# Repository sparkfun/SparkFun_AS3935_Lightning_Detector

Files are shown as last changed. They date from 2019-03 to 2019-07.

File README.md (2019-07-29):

 SparkFun AS3935 Lightning Detector
========================================

SparkFun AS3935 Lightning Detector (https://www.sparkfun.com/products/15441)

[*SparkFun AS3935 Lightning Detector (SEN-15441)*](https://www.sparkfun.com/products/15441)

The SparkFun Lightning Detector adds lightning detection to your next weather station to make sure you are aware of any potential hazardous weather heading your way. The AS3935 is capable of detecting lightning up to 40km away with an accuracy of 1km to the storm front with a sensitive antenna tuned to pick up lightning events in the 500kHz band. 

There are a number of sources that can cause false positives but the lightning detector itself can reliably filter these out by default. If not, we've made sure to include settings you can configure using the lightning detector library to increase the chip's robustness to noise and false positives. The lightning detector library also gives you access to settings such as storm sensing sensitivity when detecting indoors vs outdoors, or the number of lightning strikes needed to trigger an interrupt.

Repository Contents
-------------------

* **/Documentation** - Datasheets, additional product information
* **/Hardware** - Eagle design files (.brd, .sch)

Documentation
--------------
* **[Installing an Arduino Library](https://learn.sparkfun.com/tutorials/installing-an-arduino-library/)** - Basic instructions on installing an Arduino library
* **[Library](https://github.com/sparkfun/SparkFun_AS3935_Lightning_Detector_Arduino_Library)** - Arduino library for the AS3935 Lightning Detector
* **[Hookup Guide](https://learn.sparkfun.com/tutorials/sparkfun-as3935-lightning-detector-hookup-guide-v20)** - Hookup Guide for the SparkFun AS3935 Lightning Detector

Product Versions
--------------
* [SEN-15441](https://www.sparkfun.com/products/15441) - SparkFun SPI version
* [SEN-15276](https://www.sparkfun.com/products/15276) - SparkFun I2C version
* [SPX-15057](https://www.sparkfun.com/products/retired/15057) - SparkX version

License Information
-------------------

This product is _**open source**_! 

Please review the LICENSE.md file for license information.

If you have any questions or concerns on licensing, please contact technical support on our [SparkFun forums](https://forum.sparkfun.com/viewforum.php?f=152).

Please use, reuse, and modify these files as you see fit. Please maintain attribution to SparkFun Electronics and release under the same license.

Distributed as-is; no warranty is given.

- Your friends at SparkFun.

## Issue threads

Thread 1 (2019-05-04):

Error compiling when using Huzzah ESP8266 or Adafruit Feather M0 board

Loopbackconnector, 2019-05-04:
When compiling Example1_BasicLightning and using either Huzzah  ESP8266 or Adafruit Feather M0 as the board type I get the following error:

Example1_BasicLightning:33:38: error: invalid conversion from 'int' to 'i2cAddress {aka SF_AS3935_I2C_ADDRESS}' [-fpermissive]
 SparkFun_AS3935 lightning(AS3935_ADDR);

edspark, 2019-05-06:
Thanks for the issue, I'll get on this sometime in the next few days. Thanks for your patience!

edspark, 2019-05-09:
In the future this is best filed underneath the library [repo](https://github.com/sparkfun/SparkFun_AS3935_Lightning_Detector_Arduino_Library), since it is a library issue. It was fixed with this commit: https://github.com/sparkfun/SparkFun_AS3935_Lightning_Detector_Arduino_Library/commit/271d5d1f4748dea87de263077b5cf0d9d4602a8f

Closed 2019-05-09.

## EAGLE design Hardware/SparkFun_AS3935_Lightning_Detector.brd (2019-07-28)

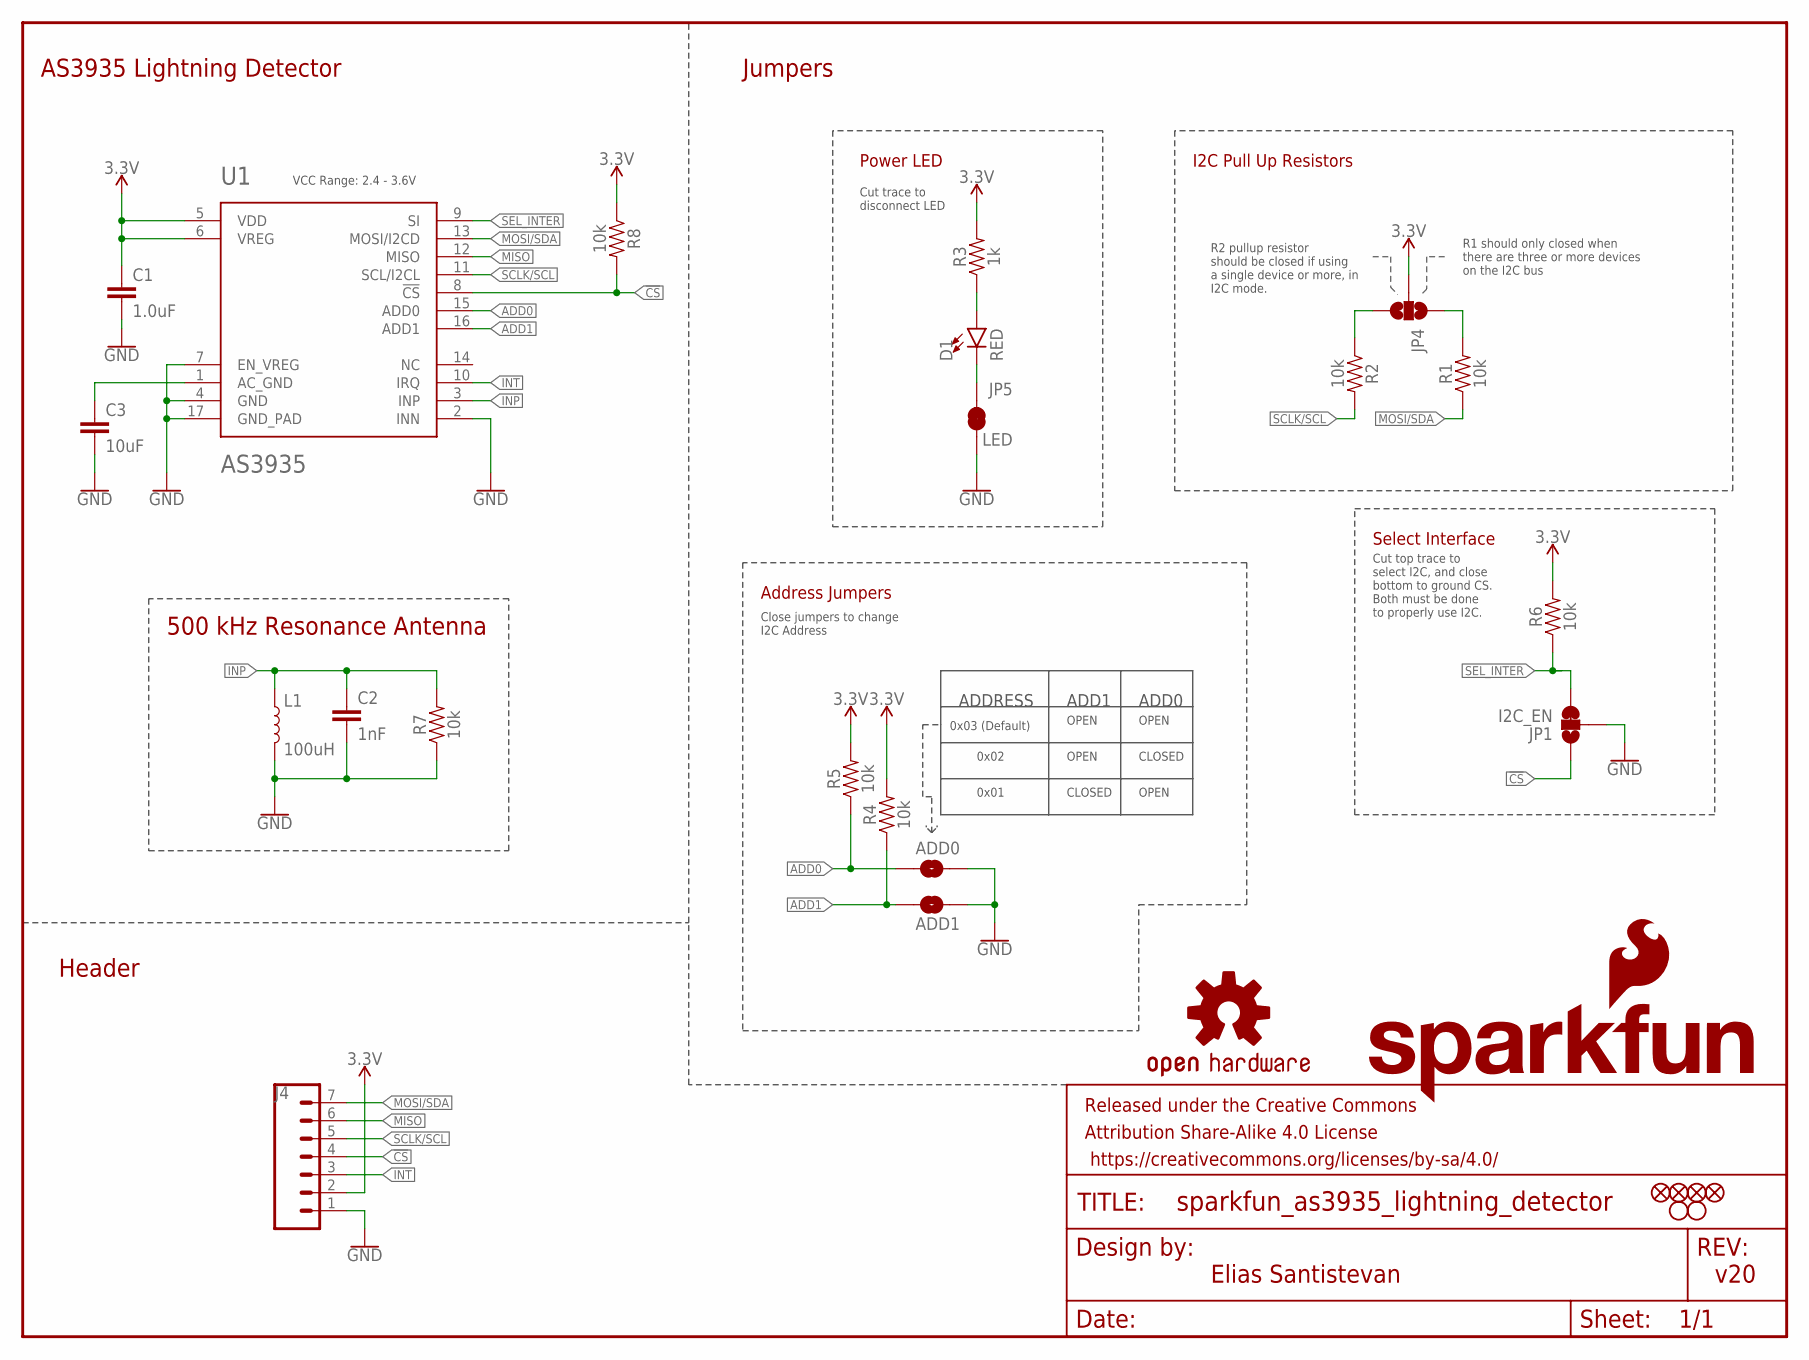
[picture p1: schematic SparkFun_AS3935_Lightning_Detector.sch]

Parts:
ADD0, ADD1: JUMPER-SMT_2_NO_SILK; SMT-JUMPER_2_NO_SILK
C1: 1.0uF; 0603
C2: 1nF; 0603
C3: 10uF; 0603
D1: RED; LED-0603
FD1, FD2, FD3, FD4: FIDUCIAL1X2; FIDUCIAL-1X2
FRAME1: FRAME-LETTER; CREATIVE_COMMONS
H1, H2: STAND-OFFTIGHT; STAND-OFF-TIGHT
J4: CONN_07NO_SILK; 1X07_NO_SILK
JP1: I2C_EN; SMT-JUMPER_3_1-NC_TRACE_SILK
JP4: JUMPER-SMT_3_NO_SILK; SMT-JUMPER_3_NO_SILK
JP5: LED; SMT-JUMPER_2_NC_TRACE_SILK
L1: 100uH; MA5532-AE
LOGO1: OSHW-LOGOS; OSHW-LOGO-S
LOGO2: SFE_LOGO_NAME.1_INCH; SFE_LOGO_NAME_.1
LOGO3: SFE_LOGO_FLAME.2_INCH; SFE_LOGO_FLAME_.2
R1, R2, R4, R5, R6, R7, R8: 10k; 0603
R3: 1k; 0603
U1: AS3935; 16LD_MLPQ

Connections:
3.3V: C1.1, J4.2, JP4.2, R3.2, R4.2, R5.2, R6.2, R8.1, U1.5 (VDD), U1.6 (VREG)
!CS: J4.4, JP1.1, R8.2, U1.8 (!CS)
ADD0: ADD0.1, R5.1, U1.15 (ADD0)
ADD1: ADD1.1, R4.1, U1.16 (ADD1)
GND: ADD0.2, ADD1.2, C1.2, C2.2, C3.2, J4.1, JP1.2, JP5.1, L1.2, R7.1, U1.2 (INN), U1.4 (GND), U1.7 (EN_VREG), U1.17 (GND_PAD)
INP: C2.1, L1.1, R7.2, U1.3 (INP)
INT: J4.3, U1.10 (IRQ)
MISO: J4.6, U1.12 (MISO)
MOSI/SDA: J4.7, R1.1, U1.13 (MOSI/I2CD)
unnamed: D1.A, R3.1
unnamed: C3.1, U1.1 (AC_GND)
unnamed: JP4.1, R1.2
unnamed: JP4.3, R2.1
unnamed: D1.C, JP5.2
SCLK/SCL: J4.5, R2.2, U1.11 (SCL/I2CL)
SEL_INTER: JP1.3, R6.1, U1.9 (SI)

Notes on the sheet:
Elias Santistevan
v20
AS3935 Lightning Detector
Jumpers
Header
500 kHz Resonance Antenna
R1 should only closed when there are three or more devices on the I2C bus
Close jumpers to change I2C Address
ADD0
ADD1
OPEN
CLOSED
ADDRESS
0x03 (Default)
0x02
VCC Range: 2.4 - 3.6V
Cut trace to disconnect LED
0x01
R2 pullup resistor should be closed if using a single device or more, in I2C mode.
Power LED
I2C Pull Up Resistors
Address Jumpers
Select Interface
Cut top trace to select I2C, and close bottom to ground CS. Both must be done to properly use I2C.

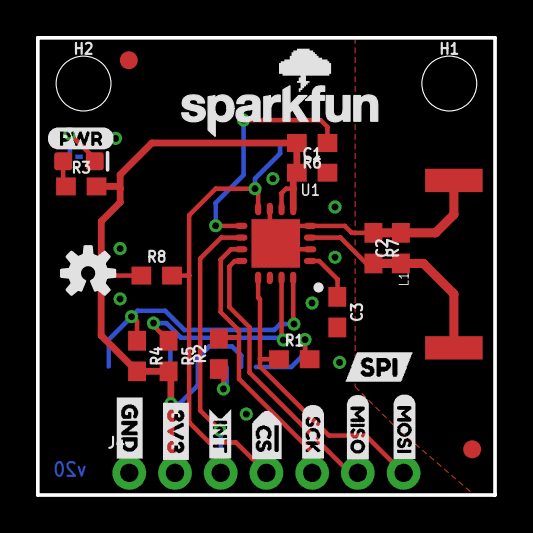
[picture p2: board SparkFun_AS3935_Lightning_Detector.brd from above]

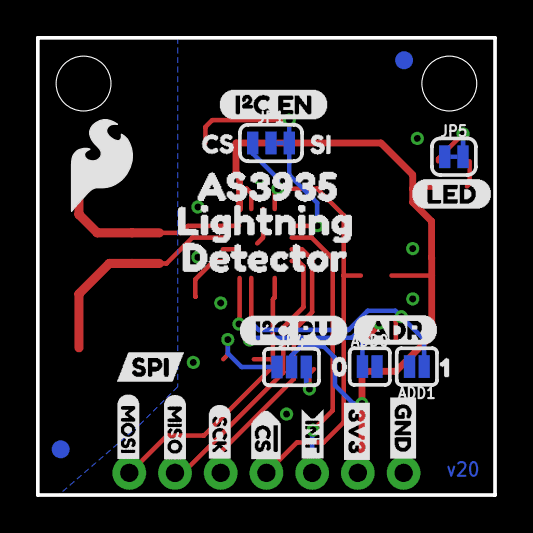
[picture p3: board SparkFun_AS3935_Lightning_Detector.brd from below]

Board: 2 copper layers, 25.4 x 25.4 mm, 59 parts (27 on the bottom side), 16 nets.

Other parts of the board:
U$1: LED0
U$2, U$10: GND-03
U$3, U$15: SPI1
U$4, U$18: 3V3-03
U$5, U$30: #CS0
U$6: AS39350
U$7: LIGHTNING0
U$8, U$23: SCK-(]-03
U$9, U$12: MISO-(]-03
U$11, U$22: MOSI-(]-03
U$13, U$14: INT0
U$16: CS0
U$17: I#C_EN0
U$19: SI1
U$32: PWR-()-03
U$33: ADR-()-04
U$34: I#C_PU0
U$36: 10
U$37: 00
U$39: DETECTOR0
U$40: ##0

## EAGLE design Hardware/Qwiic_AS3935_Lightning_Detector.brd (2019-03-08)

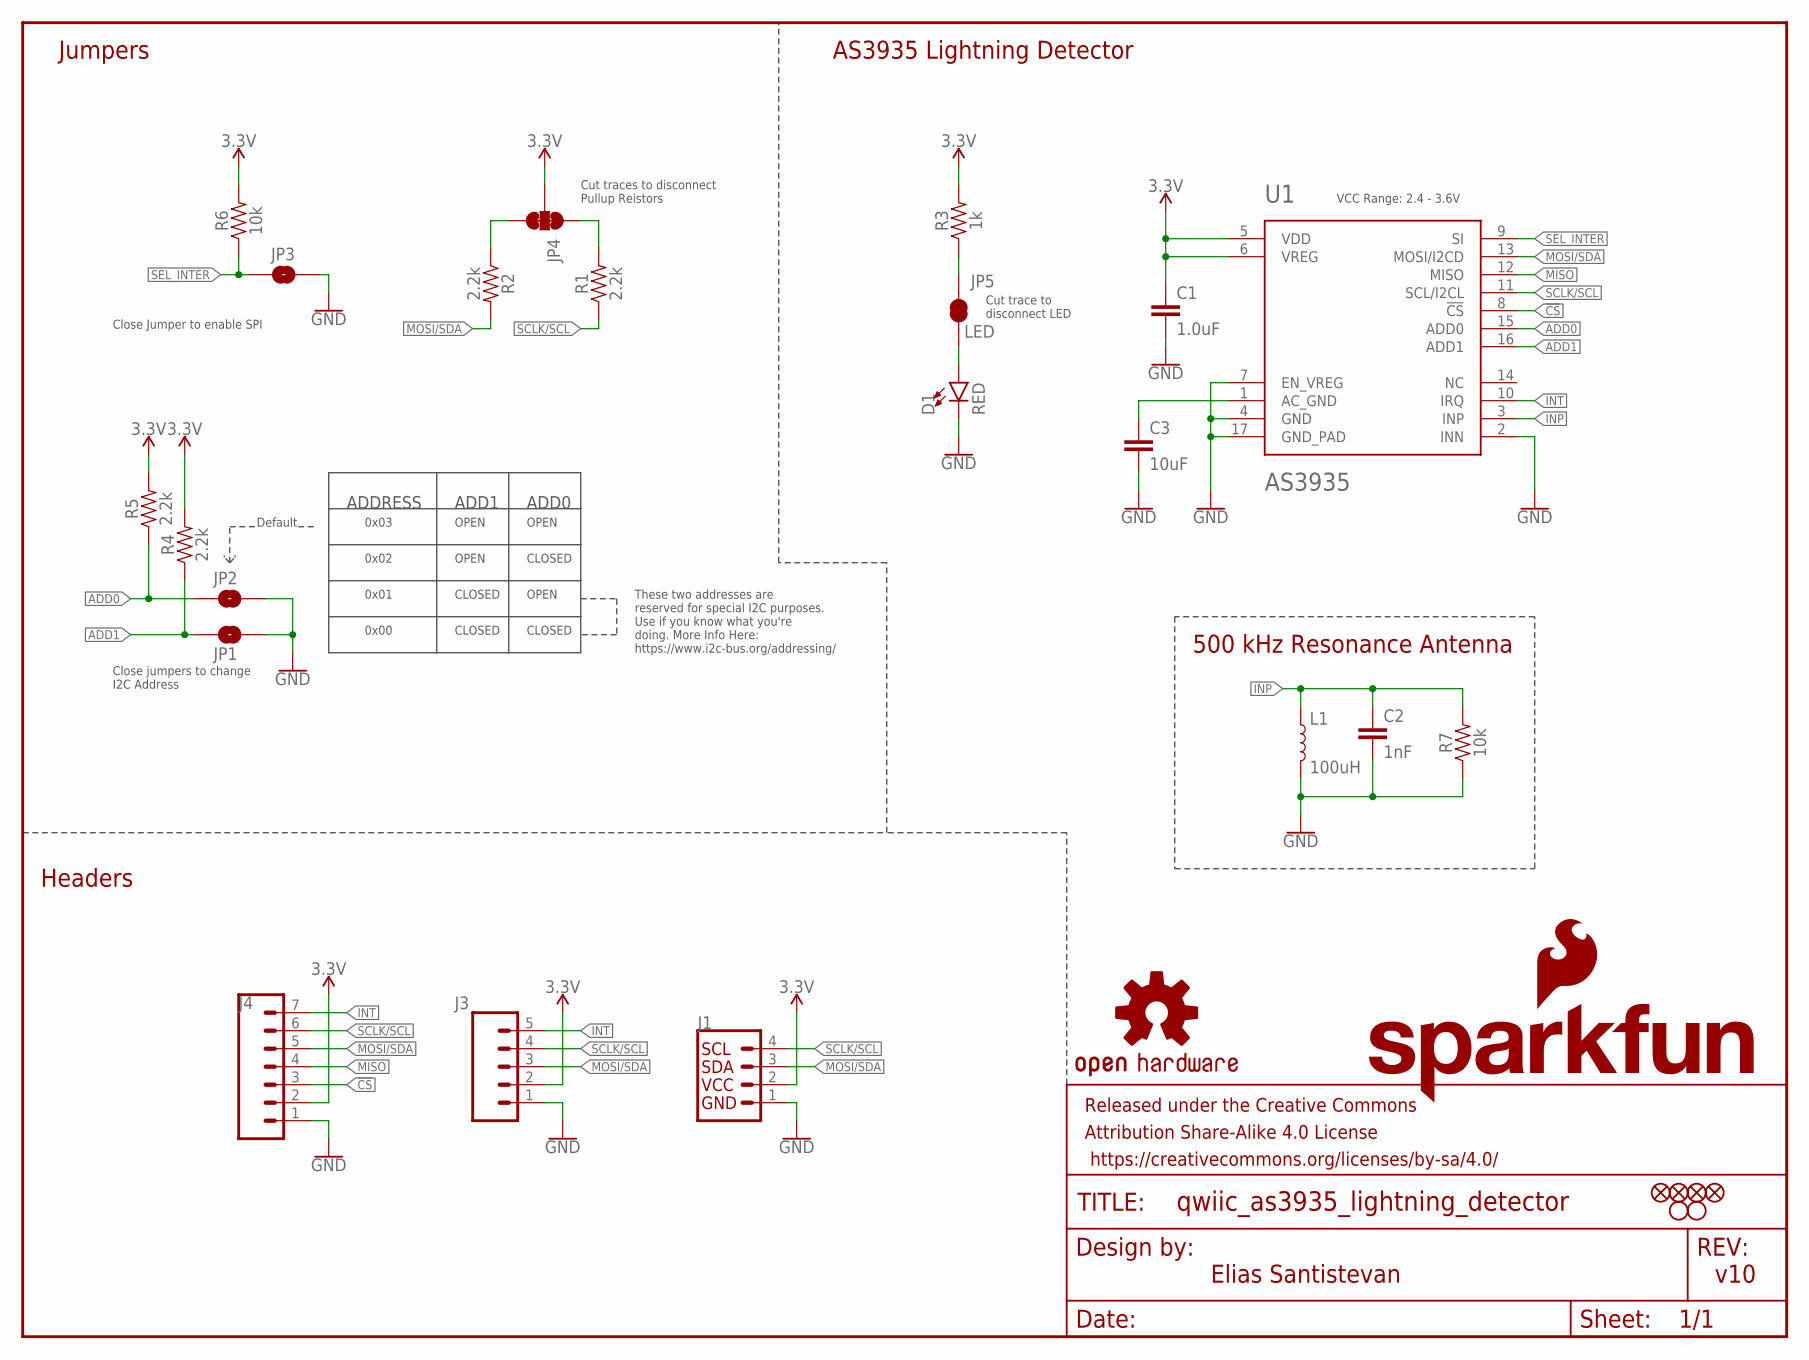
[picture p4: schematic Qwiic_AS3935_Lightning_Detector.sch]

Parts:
C1: 1.0uF; 0603
C2: 1nF; 0603
C3: 10uF; 0603
D1: RED; LED-0603
FD1, FD2, FD3, FD4: FIDUCIAL1X2; FIDUCIAL-1X2
FRAME1: FRAME-LETTER; CREATIVE_COMMONS
H1, H2: STAND-OFFTIGHT; STAND-OFF-TIGHT
J1: QWIIC_CONNECTORJS-1MM; JST04_1MM_RA
J3: CONN_05NO_SILK; 1X05_NO_SILK
J4: CONN_07NO_SILK; 1X07_NO_SILK
JP1, JP2, JP3: JUMPER-SMT_2_NO_SILK; SMT-JUMPER_2_NO_SILK
JP4: JUMPER-SMT_3_2-NC_TRACE_SILK; SMT-JUMPER_3_2-NC_TRACE_SILK
JP5: LED; SMT-JUMPER_2_NC_TRACE_SILK
L1: 100uH; MA5532-AE
LOGO1: OSHW-LOGOS; OSHW-LOGO-S
LOGO2: SFE_LOGO_NAME.1_INCH; SFE_LOGO_NAME_.1
LOGO3: SFE_LOGO_FLAME.1_INCH; SFE_LOGO_FLAME_.1
R1, R2, R4, R5: 2.2k; 0603
R3: 1k; 0603
R6, R7: 10k; 0603
U1: AS3935; 16LD_MLPQ

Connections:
3.3V: C1.1, J1.2, J3.2, J4.2, JP4.2, R3.2, R4.2, R5.2, R6.2, U1.5 (VDD), U1.6 (VREG)
!CS: J4.3, U1.8 (!CS)
ADD0: JP2.1, R5.1, U1.15 (ADD0)
ADD1: JP1.1, R4.1, U1.16 (ADD1)
GND: C1.2, C2.2, C3.2, D1.C, J1.1, J3.1, J4.1, JP1.2, JP2.2, JP3.2, L1.2, R7.1, U1.2 (INN), U1.4 (GND), U1.7 (EN_VREG), U1.17 (GND_PAD)
INP: C2.1, L1.1, R7.2, U1.3 (INP)
INT: J3.5, J4.7, U1.10 (IRQ)
MISO: J4.4, U1.12 (MISO)
MOSI/SDA: J1.3, J3.3, J4.5, R2.2, U1.13 (MOSI/I2CD)
unnamed: JP5.2, R3.1
unnamed: C3.1, U1.1 (AC_GND)
unnamed: JP4.1, R1.2
unnamed: JP4.3, R2.1
unnamed: D1.A, JP5.1
SCLK/SCL: J1.4, J3.4, J4.6, R1.1, U1.11 (SCL/I2CL)
SEL_INTER: JP3.1, R6.1, U1.9 (SI)

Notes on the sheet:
Elias Santistevan
v10
AS3935 Lightning Detector
Jumpers
Headers
500 kHz Resonance Antenna
Close Jumper to enable SPI
Cut traces to disconnect Pullup Reistors
Close jumpers to change I2C Address
ADD0
ADD1
OPEN
CLOSED
ADDRESS
0x03
0x02
Default
VCC Range: 2.4 - 3.6V
Cut trace to disconnect LED
0x01
0x00
These two addresses are reserved for special I2C purposes. Use if you know what you're doing. More Info Here: https://www.i2c-bus.org/addressing/

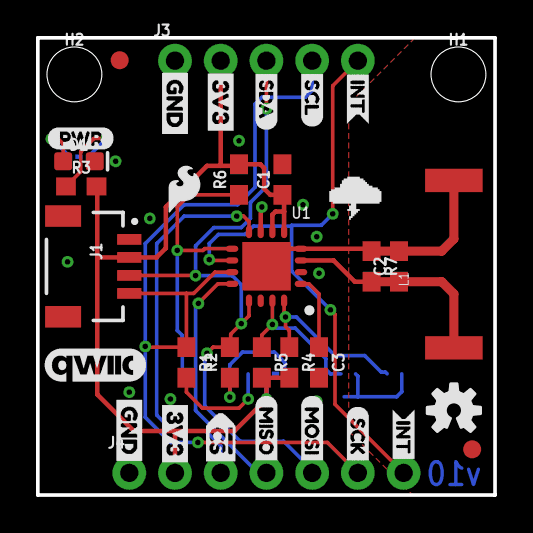
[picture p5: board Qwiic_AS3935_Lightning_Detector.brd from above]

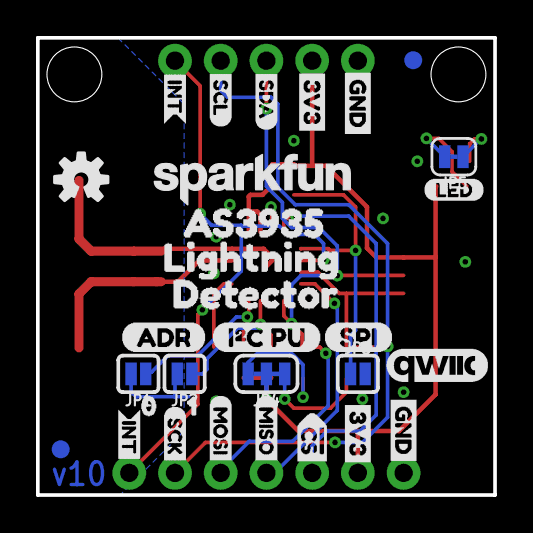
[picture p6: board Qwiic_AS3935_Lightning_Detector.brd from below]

Board: 2 copper layers, 25.4 x 25.4 mm, 69 parts (31 on the bottom side), 16 nets.

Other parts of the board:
U$1: LED0
U$3, U$4: QWIIC_COPYRIGHT_SMALL
U$6: AS39350
U$7: LIGHTNING0
U$8, U$9, U$10, U$38: GND-03
U$11: CS#-<]-04
U$12, U$13: MISO-(]-03
U$14, U$15, U$24, U$29: INT0
U$16, U$22: MOSI-(]-03
U$17, U$18, U$20, U$21: 3V3-03
U$19, U$23: SCK-(]-03
U$25, U$26: SDA0
U$27, U$28: SCL0
U$30: #CS0
U$31: OSHW-LOGO-S
U$32: PWR-()-03
U$33: ADR-()-04
U$34: I#C_PU0
U$35: SPI0
U$36: 10
U$37: 00
U$39: DETECTOR0
U$40: ##0

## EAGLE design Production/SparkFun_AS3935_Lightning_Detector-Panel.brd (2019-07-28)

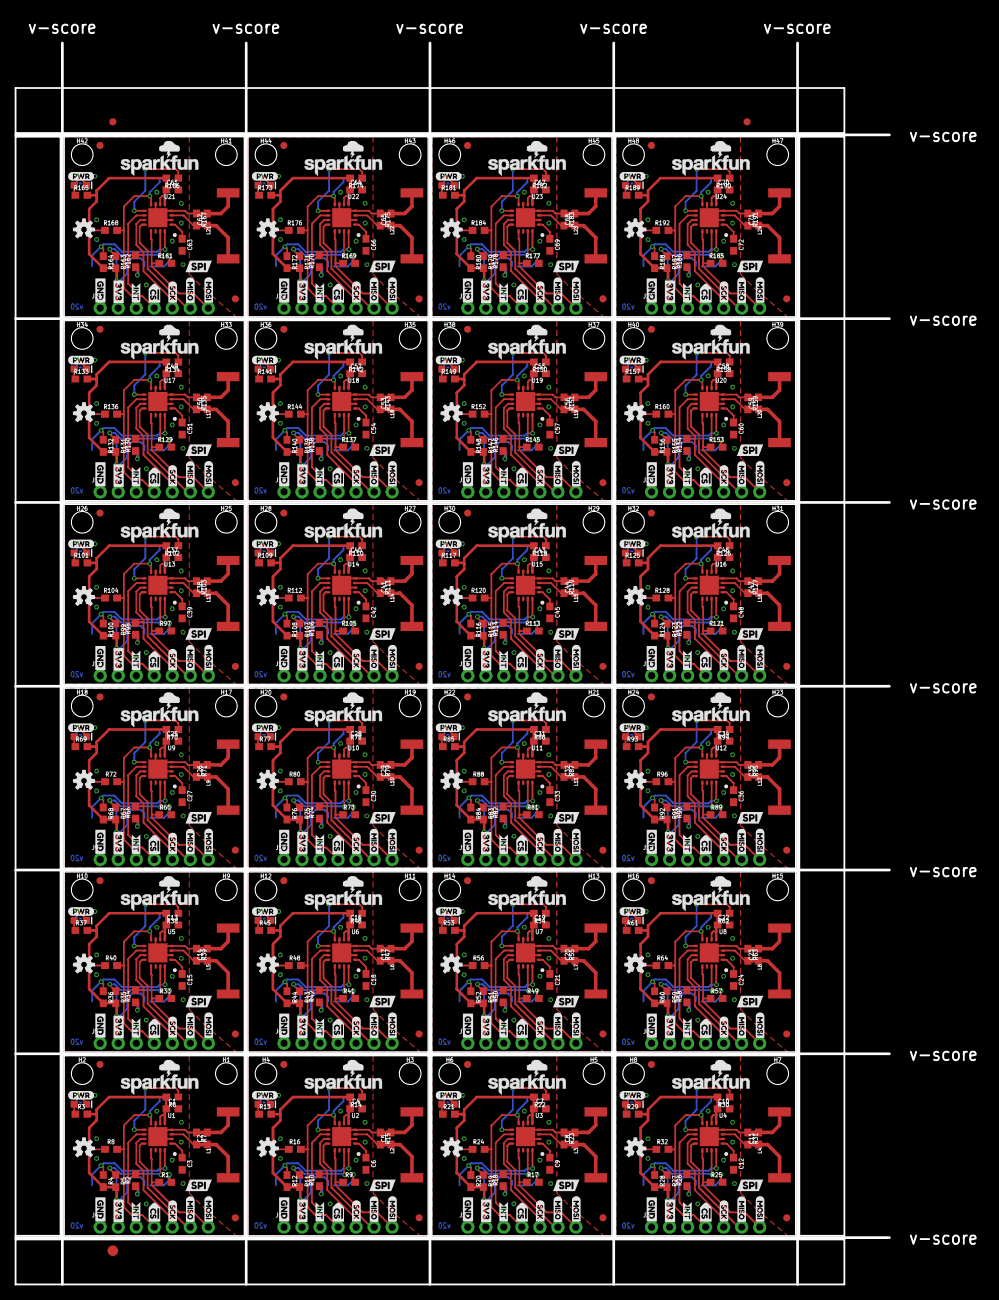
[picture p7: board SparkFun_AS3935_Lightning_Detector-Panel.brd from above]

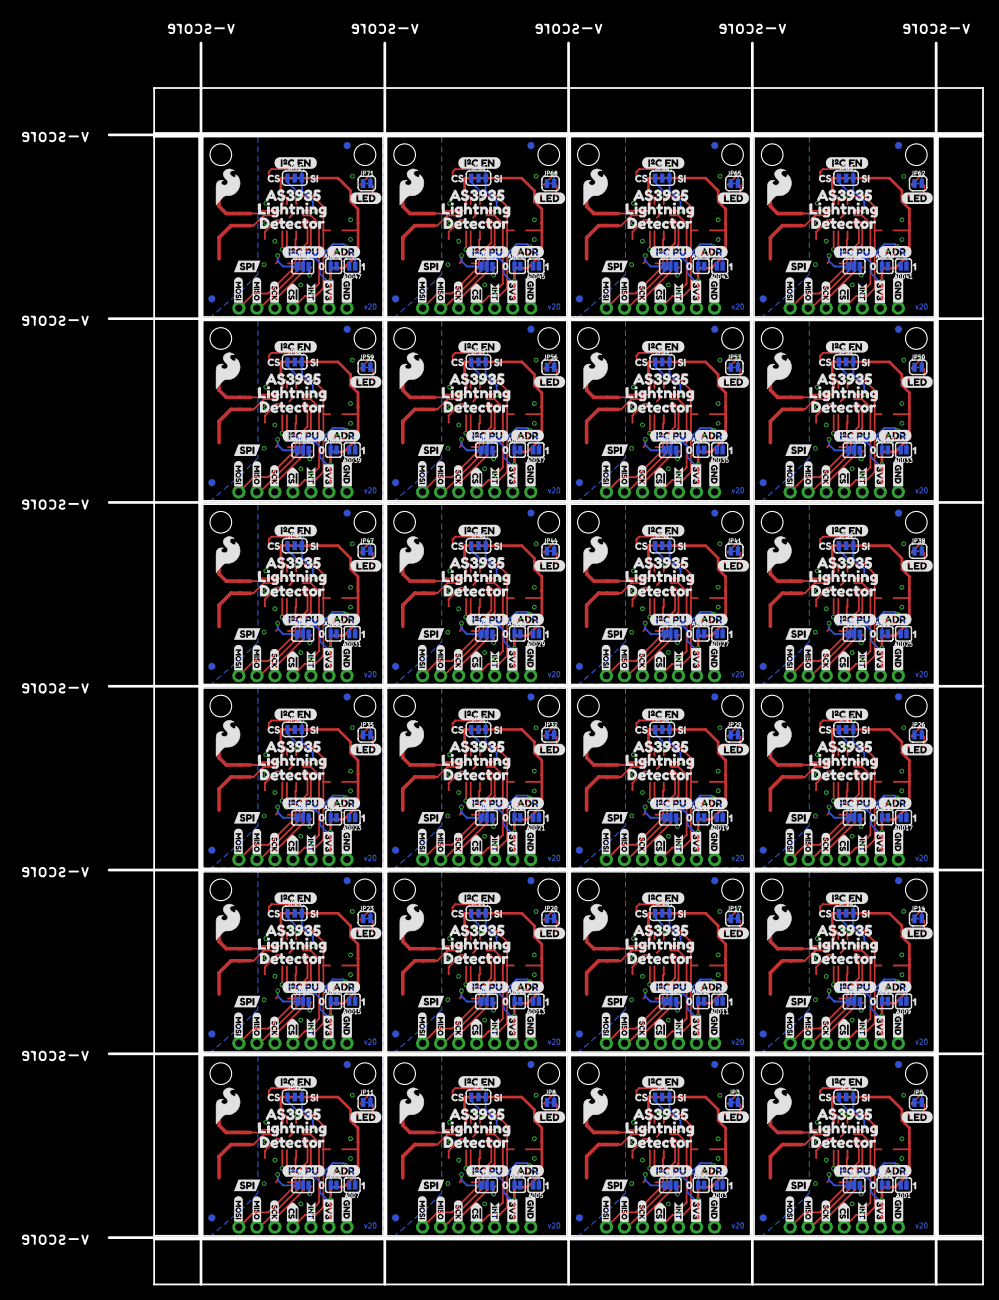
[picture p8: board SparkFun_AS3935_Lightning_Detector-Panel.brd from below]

Board: 2 copper layers, 123.2 x 175.0 mm, 1395 parts (648 on the bottom side), 384 nets.

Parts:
ADD0, ADD1, ADD2, ADD3, ADD4, ADD5, ADD6, ADD7, ADD8, ADD9, ADD10, ADD11, ADD12, ADD13, ADD14, ADD15, ADD16, ADD17, ADD18, ADD19, ADD20, ADD21, ADD22, ADD23, ADD24, ADD25, ADD26, ADD27, ADD28, ADD29, ADD30, ADD31, ADD32, ADD33, ADD34, ADD35, ADD36, ADD37, ADD38, ADD39, ADD40, ADD41, ADD42, ADD43, ADD44, ADD45, ADD46, ADD47: JUMPER-SMT_2_NO_SILK; SMT-JUMPER_2_NO_SILK
C1, C4, C7, C10, C13, C16, C19, C22, C25, C28, C31, C34, C37, C40, C43, C46, C49, C52, C55, C58, C61, C64, C67, C70: 1.0uF; 0603
C2, C5, C8, C11, C14, C17, C20, C23, C26, C29, C32, C35, C38, C41, C44, C47, C50, C53, C56, C59, C62, C65, C68, C71: 1nF; 0603
C3, C6, C9, C12, C15, C18, C21, C24, C27, C30, C33, C36, C39, C42, C45, C48, C51, C54, C57, C60, C63, C66, C69, C72: 10uF; 0603
D1, D2, D3, D4, D5, D6, D7, D8, D9, D10, D11, D12, D13, D14, D15, D16, D17, D18, D19, D20, D21, D22, D23, D24: RED; LED-0603
E$1, E$2: FIDUCIAL-1X2
E$3: FIDUCIAL-1.5X3
FD1, FD2, FD3, FD4, FD5, FD6, FD7, FD8, FD9, FD10, FD11, FD12, FD13, FD14, FD15, FD16, FD17, FD18, FD19, FD20, FD21, FD22, FD23, FD24, FD25, FD26, FD27, FD28, FD29, FD30, FD31, FD32, FD33, FD34, FD35, FD36, FD37, FD38, FD39, FD40, FD41, FD42, FD43, FD44, FD45, FD46, FD47, FD48, FD49, FD50, FD51, FD52, FD53, FD54, FD55, FD56, FD57, FD58, FD59, FD60, FD61, FD62, FD63, FD64, FD65, FD66, FD67, FD68, FD69, FD70, FD71, FD72, FD73, FD74, FD75, FD76, FD77, FD78, FD79, FD80, FD81, FD82, FD83, FD84, FD85, FD86, FD87, FD88, FD89, FD90, FD91, FD92, FD93, FD94, FD95, FD96: FIDUCIAL1X2; FIDUCIAL-1X2
H1, H2, H3, H4, H5, H6, H7, H8, H9, H10, H11, H12, H13, H14, H15, H16, H17, H18, H19, H20, H21, H22, H23, H24, H25, H26, H27, H28, H29, H30, H31, H32, H33, H34, H35, H36, H37, H38, H39, H40, H41, H42, H43, H44, H45, H46, H47, H48: STAND-OFFTIGHT; STAND-OFF-TIGHT
J1, J2, J3, J4, J5, J6, J7, J8, J9, J10, J11, J12, J13, J14, J15, J16, J17, J18, J19, J20, J21, J22, J23, J24: 1X07_NO_SILK
JP1, JP6, JP9, JP12, JP15, JP18, JP21, JP24, JP27, JP30, JP33, JP36, JP39, JP42, JP45, JP48, JP51, JP54, JP57, JP60, JP63, JP66, JP69, JP72: I2C_EN; SMT-JUMPER_3_1-NC_TRACE_SILK
JP2, JP4, JP7, JP10, JP13, JP16, JP19, JP22, JP25, JP28, JP31, JP34, JP37, JP40, JP43, JP46, JP49, JP52, JP55, JP58, JP61, JP64, JP67, JP70: JUMPER-SMT_3_NO_SILK; SMT-JUMPER_3_NO_SILK
JP3, JP5, JP8, JP11, JP14, JP17, JP20, JP23, JP26, JP29, JP32, JP35, JP38, JP41, JP44, JP47, JP50, JP53, JP56, JP59, JP62, JP65, JP68, JP71: LED; SMT-JUMPER_2_NC_TRACE_SILK
L1, L2, L3, L4, L5, L6, L7, L8, L9, L10, L11, L12, L13, L14, L15, L16, L17, L18, L19, L20, L21, L22, L23, L24: 100uH; MA5532-AE
LOGO1, LOGO4, LOGO7, LOGO10, LOGO13, LOGO16, LOGO19, LOGO22, LOGO25, LOGO28, LOGO31, LOGO34, LOGO37, LOGO40, LOGO43, LOGO46, LOGO49, LOGO52, LOGO55, LOGO58, LOGO61, LOGO64, LOGO67, LOGO70: OSHW-LOGOS; OSHW-LOGO-S
LOGO2, LOGO5, LOGO8, LOGO11, LOGO14, LOGO17, LOGO20, LOGO23, LOGO26, LOGO29, LOGO32, LOGO35, LOGO38, LOGO41, LOGO44, LOGO47, LOGO50, LOGO53, LOGO56, LOGO59, LOGO62, LOGO65, LOGO68, LOGO71: SFE_LOGO_NAME.1_INCH; SFE_LOGO_NAME_.1
LOGO3, LOGO6, LOGO9, LOGO12, LOGO15, LOGO18, LOGO21, LOGO24, LOGO27, LOGO30, LOGO33, LOGO36, LOGO39, LOGO42, LOGO45, LOGO48, LOGO51, LOGO54, LOGO57, LOGO60, LOGO63, LOGO66, LOGO69, LOGO72: SFE_LOGO_FLAME.2_INCH; SFE_LOGO_FLAME_.2
R1, R2, R4, R5, R6, R7, R8, R9, R10, R11, R12, R14, R15, R16, R17, R18, R19, R20, R22, R23, R24, R25, R26, R27, R28, R30, R31, R32, R33, R34, R35, R36, R38, R39, R40, R41, R42, R43, R44, R46, R47, R48, R49, R50, R51, R52, R54, R55, R56, R57, R58, R59, R60, R62, R63, R64, R65, R66, R67, R68, R70, R71, R72, R73, R74, R75, R76, R78, R79, R80, R81, R82, R83, R84, R86, R87, R88, R89, R90, R91, R92, R94, R95, R96, R97, R98, R99, R100, R102, R103, R104, R105, R106, R107, R108, R110, R111, R112, R113, R114, R115, R116, R118, R119, R120, R121, R122, R123, R124, R126, R127, R128, R129, R130, R131, R132, R134, R135, R136, R137, R138, R139, R140, R142, R143, R144, R145, R146, R147, R148, R150, R151, R152, R153, R154, R155, R156, R158, R159, R160, R161, R162, R163, R164, R166, R167, R168, R169, R170, R171, R172, R174, R175, R176, R177, R178, R179, R180, R182, R183, R184, R185, R186, R187, R188, R190, R191, R192: 10k; 0603
R3, R13, R21, R29, R37, R45, R53, R61, R69, R77, R85, R93, R101, R109, R117, R125, R133, R141, R149, R157, R165, R173, R181, R189: 1k; 0603
U1, U2, U3, U4, U5, U6, U7, U8, U9, U10, U11, U12, U13, U14, U15, U16, U17, U18, U19, U20, U21, U22, U23, U24: AS3935; 16LD_MLPQ
U$1, U$45, U$74, U$103, U$132, U$161, U$190, U$219, U$248, U$277, U$306, U$335, U$364, U$393, U$422, U$451, U$480, U$509, U$538, U$567, U$596, U$625, U$654, U$683: LED0
U$2, U$10, U$20, U$47, U$59, U$76, U$88, U$105, U$117, U$134, U$146, U$163, U$175, U$192, U$204, U$221, U$233, U$250, U$262, U$279, U$291, U$308, U$320, U$337, U$349, U$366, U$378, U$395, U$407, U$424, U$436, U$453, U$465, U$482, U$494, U$511, U$523, U$540, U$552, U$569, U$581, U$598, U$610, U$627, U$639, U$656, U$668, U$685: GND-03
U$3, U$15, U$46, U$53, U$75, U$82, U$104, U$111, U$133, U$140, U$162, U$169, U$191, U$198, U$220, U$227, U$249, U$256, U$278, U$285, U$307, U$314, U$336, U$343, U$365, U$372, U$394, U$401, U$423, U$430, U$452, U$459, U$481, U$488, U$510, U$517, U$539, U$546, U$568, U$575, U$597, U$604, U$626, U$633, U$655, U$662, U$684, U$691: SPI1
U$4, U$18, U$24, U$48, U$61, U$77, U$90, U$106, U$119, U$135, U$148, U$164, U$177, U$193, U$206, U$222, U$235, U$251, U$264, U$280, U$293, U$309, U$322, U$338, U$351, U$367, U$380, U$396, U$409, U$425, U$438, U$454, U$467, U$483, U$496, U$512, U$525, U$541, U$554, U$570, U$583, U$599, U$612, U$628, U$641, U$657, U$670, U$686: 3V3-03
U$5, U$30, U$44, U$49, U$73, U$78, U$102, U$107, U$131, U$136, U$160, U$165, U$189, U$194, U$218, U$223, U$247, U$252, U$276, U$281, U$305, U$310, U$334, U$339, U$363, U$368, U$392, U$397, U$421, U$426, U$450, U$455, U$479, U$484, U$508, U$513, U$537, U$542, U$566, U$571, U$595, U$600, U$624, U$629, U$653, U$658, U$682, U$687: #CS0
U$6, U$31, U$67, U$96, U$125, U$154, U$183, U$212, U$241, U$270, U$299, U$328, U$357, U$386, U$415, U$444, U$473, U$502, U$531, U$560, U$589, U$618, U$647, U$676: AS39350
U$7, U$35, U$68, U$97, U$126, U$155, U$184, U$213, U$242, U$271, U$300, U$329, U$358, U$387, U$416, U$445, U$474, U$503, U$532, U$561, U$590, U$619, U$648, U$677: LIGHTNING0
U$8, U$23, U$43, U$50, U$72, U$79, U$101, U$108, U$130, U$137, U$159, U$166, U$188, U$195, U$217, U$224, U$246, U$253, U$275, U$282, U$304, U$311, U$333, U$340, U$362, U$369, U$391, U$398, U$420, U$427, U$449, U$456, U$478, U$485, U$507, U$514, U$536, U$543, U$565, U$572, U$594, U$601, U$623, U$630, U$652, U$659, U$681, U$688: SCK-(]-03
U$9, U$12, U$21, U$51, U$60, U$80, U$89, U$109, U$118, U$138, U$147, U$167, U$176, U$196, U$205, U$225, U$234, U$254, U$263, U$283, U$292, U$312, U$321, U$341, U$350, U$370, U$379, U$399, U$408, U$428, U$437, U$457, U$466, U$486, U$495, U$515, U$524, U$544, U$553, U$573, U$582, U$602, U$611, U$631, U$640, U$660, U$669, U$689: MISO-(]-03
U$11, U$22, U$42, U$52, U$71, U$81, U$100, U$110, U$129, U$139, U$158, U$168, U$187, U$197, U$216, U$226, U$245, U$255, U$274, U$284, U$303, U$313, U$332, U$342, U$361, U$371, U$390, U$400, U$419, U$429, U$448, U$458, U$477, U$487, U$506, U$516, U$535, U$545, U$564, U$574, U$593, U$603, U$622, U$632, U$651, U$661, U$680, U$690: MOSI-(]-03
U$13, U$14, U$57, U$58, U$86, U$87, U$115, U$116, U$144, U$145, U$173, U$174, U$202, U$203, U$231, U$232, U$260, U$261, U$289, U$290, U$318, U$319, U$347, U$348, U$376, U$377, U$405, U$406, U$434, U$435, U$463, U$464, U$492, U$493, U$521, U$522, U$550, U$551, U$579, U$580, U$608, U$609, U$637, U$638, U$666, U$667, U$695, U$696: INT0
U$16, U$55, U$84, U$113, U$142, U$171, U$200, U$229, U$258, U$287, U$316, U$345, U$374, U$403, U$432, U$461, U$490, U$519, U$548, U$577, U$606, U$635, U$664, U$693: CS0
U$17, U$54, U$83, U$112, U$141, U$170, U$199, U$228, U$257, U$286, U$315, U$344, U$373, U$402, U$431, U$460, U$489, U$518, U$547, U$576, U$605, U$634, U$663, U$692: I#C_EN0
U$19, U$56, U$85, U$114, U$143, U$172, U$201, U$230, U$259, U$288, U$317, U$346, U$375, U$404, U$433, U$462, U$491, U$520, U$549, U$578, U$607, U$636, U$665, U$694: SI1
U$25, U$32, U$62, U$91, U$120, U$149, U$178, U$207, U$236, U$265, U$294, U$323, U$352, U$381, U$410, U$439, U$468, U$497, U$526, U$555, U$584, U$613, U$642, U$671: PWR-()-03
U$26, U$33, U$63, U$92, U$121, U$150, U$179, U$208, U$237, U$266, U$295, U$324, U$353, U$382, U$411, U$440, U$469, U$498, U$527, U$556, U$585, U$614, U$643, U$672: ADR-()-04
U$27, U$34, U$64, U$93, U$122, U$151, U$180, U$209, U$238, U$267, U$296, U$325, U$354, U$383, U$412, U$441, U$470, U$499, U$528, U$557, U$586, U$615, U$644, U$673: I#C_PU0
U$28, U$36, U$65, U$94, U$123, U$152, U$181, U$210, U$239, U$268, U$297, U$326, U$355, U$384, U$413, U$442, U$471, U$500, U$529, U$558, U$587, U$616, U$645, U$674: 10
U$29, U$37, U$66, U$95, U$124, U$153, U$182, U$211, U$240, U$269, U$298, U$327, U$356, U$385, U$414, U$443, U$472, U$501, U$530, U$559, U$588, U$617, U$646, U$675: 00
U$38, U$39, U$69, U$98, U$127, U$156, U$185, U$214, U$243, U$272, U$301, U$330, U$359, U$388, U$417, U$446, U$475, U$504, U$533, U$562, U$591, U$620, U$649, U$678: DETECTOR0
U$40, U$41, U$70, U$99, U$128, U$157, U$186, U$215, U$244, U$273, U$302, U$331, U$360, U$389, U$418, U$447, U$476, U$505, U$534, U$563, U$592, U$621, U$650, U$679: ##0

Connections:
3.3V: C1.1, J4.2, JP4.2, R3.2, R4.2, R5.2, R6.2, R8.1, U1.5, U1.6
3.3V1: C4.1, J1.2, JP2.2, R11.2, R12.2, R13.2, R14.2, R16.1, U2.5, U2.6
3.3V2: C7.1, J2.2, JP7.2, R19.2, R20.2, R21.2, R22.2, R24.1, U3.5, U3.6
3.3V3: C10.1, J3.2, JP10.2, R27.2, R28.2, R29.2, R30.2, R32.1, U4.5, U4.6
3.3V4: C13.1, J5.2, JP13.2, R35.2, R36.2, R37.2, R38.2, R40.1, U5.5, U5.6
3.3V5: C16.1, J6.2, JP16.2, R43.2, R44.2, R45.2, R46.2, R48.1, U6.5, U6.6
3.3V6: C19.1, J7.2, JP19.2, R51.2, R52.2, R53.2, R54.2, R56.1, U7.5, U7.6
3.3V7: C22.1, J8.2, JP22.2, R59.2, R60.2, R61.2, R62.2, R64.1, U8.5, U8.6
3.3V8: C25.1, J9.2, JP25.2, R67.2, R68.2, R69.2, R70.2, R72.1, U9.5, U9.6
3.3V9: C28.1, J10.2, JP28.2, R75.2, R76.2, R77.2, R78.2, R80.1, U10.5, U10.6
3.3V10: C31.1, J11.2, JP31.2, R83.2, R84.2, R85.2, R86.2, R88.1, U11.5, U11.6
3.3V11: C34.1, J12.2, JP34.2, R91.2, R92.2, R93.2, R94.2, R96.1, U12.5, U12.6
3.3V12: C37.1, J13.2, JP37.2, R99.2, R100.2, R101.2, R102.2, R104.1, U13.5, U13.6
3.3V13: C40.1, J14.2, JP40.2, R107.2, R108.2, R109.2, R110.2, R112.1, U14.5, U14.6
3.3V14: C43.1, J15.2, JP43.2, R115.2, R116.2, R117.2, R118.2, R120.1, U15.5, U15.6
3.3V15: C46.1, J16.2, JP46.2, R123.2, R124.2, R125.2, R126.2, R128.1, U16.5, U16.6
3.3V16: C49.1, J17.2, JP49.2, R131.2, R132.2, R133.2, R134.2, R136.1, U17.5, U17.6
3.3V17: C52.1, J18.2, JP52.2, R139.2, R140.2, R141.2, R142.2, R144.1, U18.5, U18.6
3.3V18: C55.1, J19.2, JP55.2, R147.2, R148.2, R149.2, R150.2, R152.1, U19.5, U19.6
3.3V19: C58.1, J20.2, JP58.2, R155.2, R156.2, R157.2, R158.2, R160.1, U20.5, U20.6
3.3V20: C61.1, J21.2, JP61.2, R163.2, R164.2, R165.2, R166.2, R168.1, U21.5, U21.6
3.3V21: C64.1, J22.2, JP64.2, R171.2, R172.2, R173.2, R174.2, R176.1, U22.5, U22.6
3.3V22: C67.1, J23.2, JP67.2, R179.2, R180.2, R181.2, R182.2, R184.1, U23.5, U23.6
3.3V23: C70.1, J24.2, JP70.2, R187.2, R188.2, R189.2, R190.2, R192.1, U24.5, U24.6
!CS: J4.4, JP1.1, R8.2, U1.8
!CS1: J1.4, JP6.1, R16.2, U2.8
!CS2: J2.4, JP9.1, R24.2, U3.8
!CS3: J3.4, JP12.1, R32.2, U4.8
!CS4: J5.4, JP15.1, R40.2, U5.8
!CS5: J6.4, JP18.1, R48.2, U6.8
!CS6: J7.4, JP21.1, R56.2, U7.8
!CS7: J8.4, JP24.1, R64.2, U8.8
!CS8: J9.4, JP27.1, R72.2, U9.8
!CS9: J10.4, JP30.1, R80.2, U10.8
!CS10: J11.4, JP33.1, R88.2, U11.8
!CS11: J12.4, JP36.1, R96.2, U12.8
!CS12: J13.4, JP39.1, R104.2, U13.8
!CS13: J14.4, JP42.1, R112.2, U14.8
!CS14: J15.4, JP45.1, R120.2, U15.8
!CS15: J16.4, JP48.1, R128.2, U16.8
!CS16: J17.4, JP51.1, R136.2, U17.8
!CS17: J18.4, JP54.1, R144.2, U18.8
!CS18: J19.4, JP57.1, R152.2, U19.8
!CS19: J20.4, JP60.1, R160.2, U20.8
!CS20: J21.4, JP63.1, R168.2, U21.8
!CS21: J22.4, JP66.1, R176.2, U22.8
!CS22: J23.4, JP69.1, R184.2, U23.8
!CS23: J24.4, JP72.1, R192.2, U24.8
ADD0: ADD0.1, R5.1, U1.15
ADD1: ADD1.1, R4.1, U1.16
ADD2: ADD2.1, R11.1, U2.15
ADD3: ADD3.1, R12.1, U2.16
ADD4: ADD4.1, R19.1, U3.15
ADD5: ADD5.1, R20.1, U3.16
ADD6: ADD6.1, R27.1, U4.15
ADD7: ADD7.1, R28.1, U4.16
ADD8: ADD8.1, R35.1, U5.15
ADD9: ADD9.1, R36.1, U5.16
ADD10: ADD10.1, R43.1, U6.15
ADD11: ADD11.1, R44.1, U6.16
ADD12: ADD12.1, R51.1, U7.15
ADD13: ADD13.1, R52.1, U7.16
ADD14: ADD14.1, R59.1, U8.15
ADD15: ADD15.1, R60.1, U8.16
ADD16: ADD16.1, R67.1, U9.15
ADD17: ADD17.1, R68.1, U9.16
ADD18: ADD18.1, R75.1, U10.15
ADD19: ADD19.1, R76.1, U10.16
ADD20: ADD20.1, R83.1, U11.15
ADD21: ADD21.1, R84.1, U11.16
ADD22: ADD22.1, R91.1, U12.15
ADD23: ADD23.1, R92.1, U12.16
ADD24: ADD24.1, R99.1, U13.15
ADD25: ADD25.1, R100.1, U13.16
ADD26: ADD26.1, R107.1, U14.15
ADD27: ADD27.1, R108.1, U14.16
ADD28: ADD28.1, R115.1, U15.15
ADD29: ADD29.1, R116.1, U15.16
ADD30: ADD30.1, R123.1, U16.15
ADD31: ADD31.1, R124.1, U16.16
ADD32: ADD32.1, R131.1, U17.15
ADD33: ADD33.1, R132.1, U17.16
ADD34: ADD34.1, R139.1, U18.15
ADD35: ADD35.1, R140.1, U18.16
ADD36: ADD36.1, R147.1, U19.15
ADD37: ADD37.1, R148.1, U19.16
ADD38: ADD38.1, R155.1, U20.15
ADD39: ADD39.1, R156.1, U20.16
ADD40: ADD40.1, R163.1, U21.15
ADD41: ADD41.1, R164.1, U21.16
ADD42: ADD42.1, R171.1, U22.15
ADD43: ADD43.1, R172.1, U22.16
ADD44: ADD44.1, R179.1, U23.15
ADD45: ADD45.1, R180.1, U23.16
ADD46: ADD46.1, R187.1, U24.15
ADD47: ADD47.1, R188.1, U24.16
GND: ADD0.2, ADD1.2, C1.2, C2.2, C3.2, J4.1, JP1.2, JP5.1, L1.2, R7.1, U1.2, U1.4, U1.7, U1.17
GND1: ADD2.2, ADD3.2, C4.2, C5.2, C6.2, J1.1, JP3.1, JP6.2, L2.2, R15.1, U2.2, U2.4, U2.7, U2.17
GND2: ADD4.2, ADD5.2, C7.2, C8.2, C9.2, J2.1, JP8.1, JP9.2, L3.2, R23.1, U3.2, U3.4, U3.7, U3.17
GND3: ADD6.2, ADD7.2, C10.2, C11.2, C12.2, J3.1, JP11.1, JP12.2, L4.2, R31.1, U4.2, U4.4, U4.7, U4.17
GND4: ADD8.2, ADD9.2, C13.2, C14.2, C15.2, J5.1, JP14.1, JP15.2, L5.2, R39.1, U5.2, U5.4, U5.7, U5.17
GND5: ADD10.2, ADD11.2, C16.2, C17.2, C18.2, J6.1, JP17.1, JP18.2, L6.2, R47.1, U6.2, U6.4, U6.7, U6.17
GND6: ADD12.2, ADD13.2, C19.2, C20.2, C21.2, J7.1, JP20.1, JP21.2, L7.2, R55.1, U7.2, U7.4, U7.7, U7.17
GND7: ADD14.2, ADD15.2, C22.2, C23.2, C24.2, J8.1, JP23.1, JP24.2, L8.2, R63.1, U8.2, U8.4, U8.7, U8.17
GND8: ADD16.2, ADD17.2, C25.2, C26.2, C27.2, J9.1, JP26.1, JP27.2, L9.2, R71.1, U9.2, U9.4, U9.7, U9.17
GND9: ADD18.2, ADD19.2, C28.2, C29.2, C30.2, J10.1, JP29.1, JP30.2, L10.2, R79.1, U10.2, U10.4, U10.7, U10.17
GND10: ADD20.2, ADD21.2, C31.2, C32.2, C33.2, J11.1, JP32.1, JP33.2, L11.2, R87.1, U11.2, U11.4, U11.7, U11.17
GND11: ADD22.2, ADD23.2, C34.2, C35.2, C36.2, J12.1, JP35.1, JP36.2, L12.2, R95.1, U12.2, U12.4, U12.7, U12.17
GND12: ADD24.2, ADD25.2, C37.2, C38.2, C39.2, J13.1, JP38.1, JP39.2, L13.2, R103.1, U13.2, U13.4, U13.7, U13.17
GND13: ADD26.2, ADD27.2, C40.2, C41.2, C42.2, J14.1, JP41.1, JP42.2, L14.2, R111.1, U14.2, U14.4, U14.7, U14.17
GND14: ADD28.2, ADD29.2, C43.2, C44.2, C45.2, J15.1, JP44.1, JP45.2, L15.2, R119.1, U15.2, U15.4, U15.7, U15.17
GND15: ADD30.2, ADD31.2, C46.2, C47.2, C48.2, J16.1, JP47.1, JP48.2, L16.2, R127.1, U16.2, U16.4, U16.7, U16.17
GND16: ADD32.2, ADD33.2, C49.2, C50.2, C51.2, J17.1, JP50.1, JP51.2, L17.2, R135.1, U17.2, U17.4, U17.7, U17.17
GND17: ADD34.2, ADD35.2, C52.2, C53.2, C54.2, J18.1, JP53.1, JP54.2, L18.2, R143.1, U18.2, U18.4, U18.7, U18.17
GND18: ADD36.2, ADD37.2, C55.2, C56.2, C57.2, J19.1, JP56.1, JP57.2, L19.2, R151.1, U19.2, U19.4, U19.7, U19.17
GND19: ADD38.2, ADD39.2, C58.2, C59.2, C60.2, J20.1, JP59.1, JP60.2, L20.2, R159.1, U20.2, U20.4, U20.7, U20.17
GND20: ADD40.2, ADD41.2, C61.2, C62.2, C63.2, J21.1, JP62.1, JP63.2, L21.2, R167.1, U21.2, U21.4, U21.7, U21.17
GND21: ADD42.2, ADD43.2, C64.2, C65.2, C66.2, J22.1, JP65.1, JP66.2, L22.2, R175.1, U22.2, U22.4, U22.7, U22.17
GND22: ADD44.2, ADD45.2, C67.2, C68.2, C69.2, J23.1, JP68.1, JP69.2, L23.2, R183.1, U23.2, U23.4, U23.7, U23.17
GND23: ADD46.2, ADD47.2, C70.2, C71.2, C72.2, J24.1, JP71.1, JP72.2, L24.2, R191.1, U24.2, U24.4, U24.7, U24.17
INP: C2.1, L1.1, R7.2, U1.3
INP1: C5.1, L2.1, R15.2, U2.3
INP2: C8.1, L3.1, R23.2, U3.3
INP3: C11.1, L4.1, R31.2, U4.3
INP4: C14.1, L5.1, R39.2, U5.3
INP5: C17.1, L6.1, R47.2, U6.3
INP6: C20.1, L7.1, R55.2, U7.3
INP7: C23.1, L8.1, R63.2, U8.3
INP8: C26.1, L9.1, R71.2, U9.3
INP9: C29.1, L10.1, R79.2, U10.3
INP10: C32.1, L11.1, R87.2, U11.3
INP11: C35.1, L12.1, R95.2, U12.3
INP12: C38.1, L13.1, R103.2, U13.3
INP13: C41.1, L14.1, R111.2, U14.3
INP14: C44.1, L15.1, R119.2, U15.3
INP15: C47.1, L16.1, R127.2, U16.3
INP16: C50.1, L17.1, R135.2, U17.3
INP17: C53.1, L18.1, R143.2, U18.3
INP18: C56.1, L19.1, R151.2, U19.3
INP19: C59.1, L20.1, R159.2, U20.3
INP20: C62.1, L21.1, R167.2, U21.3
INP21: C65.1, L22.1, R175.2, U22.3
INP22: C68.1, L23.1, R183.2, U23.3
INP23: C71.1, L24.1, R191.2, U24.3
INT: J4.3, U1.10
INT1: J1.3, U2.10
INT2: J2.3, U3.10
INT3: J3.3, U4.10
INT4: J5.3, U5.10
INT5: J6.3, U6.10
INT6: J7.3, U7.10
INT7: J8.3, U8.10
INT8: J9.3, U9.10
INT9: J10.3, U10.10
INT10: J11.3, U11.10
INT11: J12.3, U12.10
INT12: J13.3, U13.10
INT13: J14.3, U14.10
INT14: J15.3, U15.10
INT15: J16.3, U16.10
INT16: J17.3, U17.10
INT17: J18.3, U18.10
INT18: J19.3, U19.10
INT19: J20.3, U20.10
INT20: J21.3, U21.10
INT21: J22.3, U22.10
INT22: J23.3, U23.10
INT23: J24.3, U24.10
MISO: J4.6, U1.12
MISO1: J1.6, U2.12
MISO2: J2.6, U3.12
MISO3: J3.6, U4.12
MISO4: J5.6, U5.12
MISO5: J6.6, U6.12
MISO6: J7.6, U7.12
MISO7: J8.6, U8.12
MISO8: J9.6, U9.12
MISO9: J10.6, U10.12
MISO10: J11.6, U11.12
MISO11: J12.6, U12.12
MISO12: J13.6, U13.12
MISO13: J14.6, U14.12
MISO14: J15.6, U15.12
MISO15: J16.6, U16.12
MISO16: J17.6, U17.12
MISO17: J18.6, U18.12
MISO18: J19.6, U19.12
MISO19: J20.6, U20.12
MISO20: J21.6, U21.12
MISO21: J22.6, U22.12
MISO22: J23.6, U23.12
MISO23: J24.6, U24.12
MOSI/SDA: J4.7, R1.1, U1.13
MOSI/SDA1: J1.7, R9.1, U2.13
MOSI/SDA2: J2.7, R17.1, U3.13
MOSI/SDA3: J3.7, R25.1, U4.13
MOSI/SDA4: J5.7, R33.1, U5.13
MOSI/SDA5: J6.7, R41.1, U6.13
MOSI/SDA6: J7.7, R49.1, U7.13
MOSI/SDA7: J8.7, R57.1, U8.13
MOSI/SDA8: J9.7, R65.1, U9.13
MOSI/SDA9: J10.7, R73.1, U10.13
MOSI/SDA10: J11.7, R81.1, U11.13
MOSI/SDA11: J12.7, R89.1, U12.13
MOSI/SDA12: J13.7, R97.1, U13.13
MOSI/SDA13: J14.7, R105.1, U14.13
MOSI/SDA14: J15.7, R113.1, U15.13
MOSI/SDA15: J16.7, R121.1, U16.13
MOSI/SDA16: J17.7, R129.1, U17.13
MOSI/SDA17: J18.7, R137.1, U18.13
MOSI/SDA18: J19.7, R145.1, U19.13
MOSI/SDA19: J20.7, R153.1, U20.13
MOSI/SDA20: J21.7, R161.1, U21.13
MOSI/SDA21: J22.7, R169.1, U22.13
MOSI/SDA22: J23.7, R177.1, U23.13
MOSI/SDA23: J24.7, R185.1, U24.13
unnamed: D1.A, R3.1
unnamed: C3.1, U1.1
unnamed: JP4.1, R1.2
unnamed: JP4.3, R2.1
unnamed: D1.C, JP5.2
unnamed: C6.1, U2.1
unnamed: JP2.1, R9.2
unnamed: JP2.3, R10.1
unnamed: D2.A, R13.1
unnamed: D2.C, JP3.2
unnamed: C9.1, U3.1
unnamed: JP7.1, R17.2
unnamed: JP7.3, R18.1
unnamed: D3.A, R21.1
unnamed: D3.C, JP8.2
unnamed: C12.1, U4.1
unnamed: JP10.1, R25.2
unnamed: JP10.3, R26.1
unnamed: D4.A, R29.1
unnamed: D4.C, JP11.2
unnamed: C15.1, U5.1
unnamed: JP13.1, R33.2
unnamed: JP13.3, R34.1
unnamed: D5.A, R37.1
unnamed: D5.C, JP14.2
unnamed: C18.1, U6.1
unnamed: JP16.1, R41.2
unnamed: JP16.3, R42.1
unnamed: D6.A, R45.1
unnamed: D6.C, JP17.2
unnamed: C21.1, U7.1
unnamed: JP19.1, R49.2
unnamed: JP19.3, R50.1
unnamed: D7.A, R53.1
unnamed: D7.C, JP20.2
unnamed: C24.1, U8.1
unnamed: JP22.1, R57.2
unnamed: JP22.3, R58.1
unnamed: D8.A, R61.1
unnamed: D8.C, JP23.2
unnamed: C27.1, U9.1
unnamed: JP25.1, R65.2
unnamed: JP25.3, R66.1
unnamed: D9.A, R69.1
unnamed: D9.C, JP26.2
unnamed: C30.1, U10.1
unnamed: JP28.1, R73.2
unnamed: JP28.3, R74.1
unnamed: D10.A, R77.1
unnamed: D10.C, JP29.2
unnamed: C33.1, U11.1
unnamed: JP31.1, R81.2
unnamed: JP31.3, R82.1
unnamed: D11.A, R85.1
unnamed: D11.C, JP32.2
unnamed: C36.1, U12.1
unnamed: JP34.1, R89.2
unnamed: JP34.3, R90.1
unnamed: D12.A, R93.1
unnamed: D12.C, JP35.2
unnamed: C39.1, U13.1
unnamed: JP37.1, R97.2
unnamed: JP37.3, R98.1
unnamed: D13.A, R101.1
unnamed: D13.C, JP38.2
unnamed: C42.1, U14.1
unnamed: JP40.1, R105.2
unnamed: JP40.3, R106.1
unnamed: D14.A, R109.1
unnamed: D14.C, JP41.2
unnamed: C45.1, U15.1
unnamed: JP43.1, R113.2
unnamed: JP43.3, R114.1
unnamed: D15.A, R117.1
unnamed: D15.C, JP44.2
unnamed: C48.1, U16.1
unnamed: JP46.1, R121.2
unnamed: JP46.3, R122.1
unnamed: D16.A, R125.1
unnamed: D16.C, JP47.2
unnamed: C51.1, U17.1
unnamed: JP49.1, R129.2
unnamed: JP49.3, R130.1
unnamed: D17.A, R133.1
unnamed: D17.C, JP50.2
unnamed: C54.1, U18.1
unnamed: JP52.1, R137.2
unnamed: JP52.3, R138.1
unnamed: D18.A, R141.1
unnamed: D18.C, JP53.2
unnamed: C57.1, U19.1
unnamed: JP55.1, R145.2
unnamed: JP55.3, R146.1
unnamed: D19.A, R149.1
unnamed: D19.C, JP56.2
unnamed: C60.1, U20.1
unnamed: JP58.1, R153.2
unnamed: JP58.3, R154.1
unnamed: D20.A, R157.1
unnamed: D20.C, JP59.2
unnamed: C63.1, U21.1
unnamed: JP61.1, R161.2
unnamed: JP61.3, R162.1
unnamed: D21.A, R165.1
unnamed: D21.C, JP62.2
unnamed: C66.1, U22.1
unnamed: JP64.1, R169.2
unnamed: JP64.3, R170.1
unnamed: D22.A, R173.1
unnamed: D22.C, JP65.2
unnamed: C69.1, U23.1
unnamed: JP67.1, R177.2
unnamed: JP67.3, R178.1
unnamed: D23.A, R181.1
unnamed: D23.C, JP68.2
unnamed: C72.1, U24.1
unnamed: JP70.1, R185.2
unnamed: JP70.3, R186.1
unnamed: D24.A, R189.1
unnamed: D24.C, JP71.2
SCLK/SCL: J4.5, R2.2, U1.11
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

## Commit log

2019-03-01 Initial Commit - transfered files from SparkX repo
    [Qwiic_AS3935_Lightning_Detector.brd, Qwiic_AS3935_Lightning_Detector.sch]
2019-03-01 Adds SparkFun related silk, adds parts that were added to Eagle libraries
    [Qwiic_AS3935_Lightning_Detector.brd, Qwiic_AS3935_Lightning_Detector.sch]
2019-03-05 Replaces lightning detector - lightning detector was moved to correct library and so needed to be replaced in design
    * Changes pull up resistor on the select interface line with a 10k
    * Changes the wording of the address info box in the schematic to open/close rather
    than high/low
    [Qwiic_AS3935_Lightning_Detector.brd, Qwiic_AS3935_Lightning_Detector.sch]
2019-03-05 Fixes clearance issues after changing DRC to SparkFun-tight.drc, Adds disconnect jumper to power LED
    [Qwiic_AS3935_Lightning_Detector.brd, Qwiic_AS3935_Lightning_Detector.sch]
2019-03-08 Moves drill hits near standoff, moves LED jumper down, renames IRQ net to INT, and adds info on other address options
    [Qwiic_AS3935_Lightning_Detector.brd, Qwiic_AS3935_Lightning_Detector.sch]
2019-03-08 Updates lightning detector part to latest - window pane of paste rather than solid block
    [Qwiic_AS3935_Lightning_Detector.brd, Qwiic_AS3935_Lightning_Detector.sch]
2019-04-24 Removes temp library, the part has been included in the SparkFun Eagle Sensors Library
2019-05-16 List of changes in description from v10 to v11
    * Changes three way pull up jumper to disinclude I2C data line - also changes values to 10k
    * Removes seperate I2C header and combines I2C and SPI into one header - prevents extraneous trace length on data lines
    * Improves layout for better ground pour
    * Moves address jumpers and SPI select jumpers
    [Qwiic_AS3935_Lightning_Detector.brd, Qwiic_AS3935_Lightning_Detector.sch]
2019-05-17 Improves silk
    [Qwiic_AS3935_Lightning_Detector.brd]
2019-05-17 Adds "NC" silk, and updates info text in schematic for pullup resistors
    [Qwiic_AS3935_Lightning_Detector.brd, Qwiic_AS3935_Lightning_Detector.sch]
2019-05-17 Adds flame to underside (hur hur), adds additional path in bottom pour. changes jumper names to address rather than jumper
    [Qwiic_AS3935_Lightning_Detector.brd, Qwiic_AS3935_Lightning_Detector.sch]
2019-05-17 Fixes LED label
    [Qwiic_AS3935_Lightning_Detector.brd]
2019-05-17 Adds gerbers
    [Qwiic_AS3935_Lightning_Detector.GBL, Qwiic_AS3935_Lightning_Detector.GBO, Qwiic_AS3935_Lightning_Detector.GBS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]
2019-06-17 Removes old production files, updates board to default to SPI....
    * Changes three way jumper to normally open - only need pull ups for I2C mode
    * Changes interface select jumper to normally closed (SPI selection)
    * Updates notes on both jumpers for these modes
    * Removes Qwiic Header
    [Qwiic_AS3935_Lightning_Detector.GBL, Qwiic_AS3935_Lightning_Detector.GBO, Qwiic_AS3935_Lightning_Detector.GBS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]
2019-06-17 Changes names of board files and does nothing else
    [SparkFun_AS3935_Lightning_Detector.brd, SparkFun_AS3935_Lightning_Detector.sch]
2019-06-17 Fixes various trace errors caused by jumper swap in previous commit
    [SparkFun_AS3935_Lightning_Detector.brd]
2019-06-17 Updates jumper on underside to read I2C rather than SPI
    [SparkFun_AS3935_Lightning_Detector.brd]
2019-06-17 Fixes minor issues, changes i2c enable jumper label
    [SparkFun_AS3935_Lightning_Detector.brd]
2019-06-17 Changes chip select pull down to pullup.
    [SparkFun_AS3935_Lightning_Detector.brd, SparkFun_AS3935_Lightning_Detector.sch]
2019-06-18 Adds three way jumper for switching to I2C, one that also includes a way to ground Chip select
    [SparkFun_AS3935_Lightning_Detector.brd, SparkFun_AS3935_Lightning_Detector.sch]
2019-06-20 Changes VCC range font to vector
    [SparkFun_AS3935_Lightning_Detector.sch]
2019-06-20 Adds measurements for the standoff holes, rotates CS and SI silk, removes some wire stubs.
    [SparkFun_AS3935_Lightning_Detector.brd]
2019-06-20 Fixes measurement on wrong layer
    [SparkFun_AS3935_Lightning_Detector.brd]
2019-06-20 Adds production files
    [SparkFun_AS3935_Lightning_Detector-Panel.brd]
2019-07-23 Fixes interrupt label
    [SparkFun_AS3935_Lightning_Detector.brd]
2019-07-23 Fixes interrupt label and repanelizes product
    [SparkFun_AS3935_Lightning_Detector-Panel.brd]

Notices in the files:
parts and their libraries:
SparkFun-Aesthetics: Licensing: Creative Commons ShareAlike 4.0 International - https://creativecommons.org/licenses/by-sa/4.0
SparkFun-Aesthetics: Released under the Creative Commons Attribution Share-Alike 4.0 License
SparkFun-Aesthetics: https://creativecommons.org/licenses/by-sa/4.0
